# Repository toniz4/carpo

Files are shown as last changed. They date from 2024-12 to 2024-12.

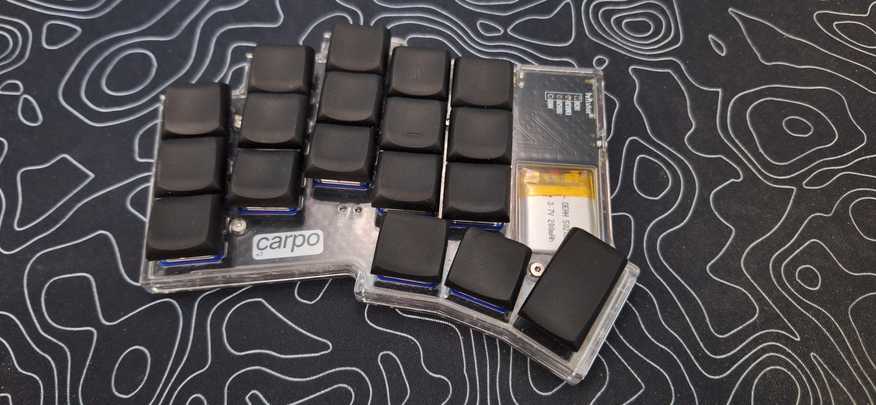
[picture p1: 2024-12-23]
assets/carpo_single.jpg

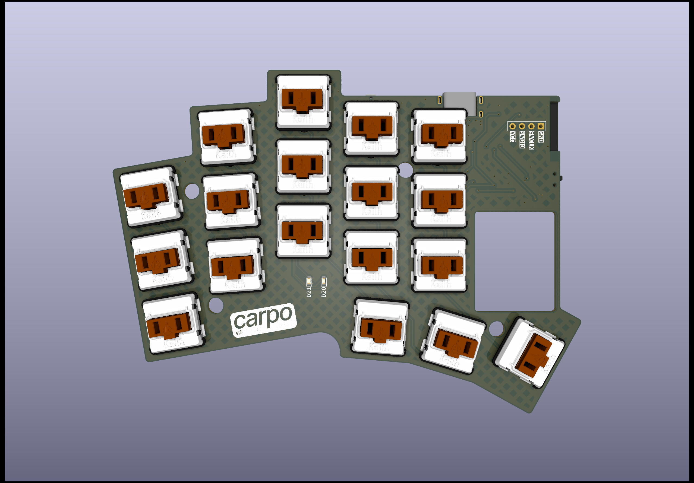
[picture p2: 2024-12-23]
assets/carpo_pcb_render_top.png

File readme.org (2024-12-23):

#+BEGIN_HTML html
<picture align="center">
  <source media="(prefers-color-scheme: dark)" srcset="/assets/carpo_logo_dark.svg">
  <source media="(prefers-color-scheme: light)" srcset="/assets/carpo_logo_light.svg">
  <img alt="carpo logo" src="/assets/carpo_logo_light.svg">
</picture>
#+END_HTML

Carpo is a 36 keys, low profile, choc spaced, split keyboard. Based on the Holyiot 18010 BLE module.

It features kailh choc v1 switches, a 200mah battery, status led and a thin and sleek case.

#+BEGIN_HTML html
<img alt="carpo both" src="/assets/carpo_both.jpg">
<details>
<summary>More photos</summary>
<img alt="carpo bottom" src="/assets/carpo_bottom.jpg">
<img alt="carpo single" src="/assets/carpo_single.jpg">
<p>The case is printed in JLCPCB using the 8001 resin</p>
<p>The keycaps are Pseudoku's Chicago Stenographer, printed in JLCPCB using the JLC black resin.</p>

<h2>PCB renders</h2>
<img alt="carpo pcb render top" src="/assets/carpo_pcb_render_top.png">
<img alt="carpo pcb render bottom" src="/assets/carpo_pcb_render_bottom.png">
</details>
#+END_HTML

The blue status LED will blink showing the Bluetooth status, if it's breathing it's disconnected. After connecting, it will blink a number of times, corresponding to the index of the current Bluetooth profile (profile 0 will blink 1 time, profile 1, 2 times, etc.)

** PCB

The PCB gerbers are in [[./pcb/gerbers/left_gerber.zip]] and [[./pcb/gerbers/right_gerber.zip]]

*** BOM

This is the BOM for a single side, duplicate the quantity for both sides.

|------------+------------------------+-----+----------+------------|
| Reference  | Value                  | Qty | LCSC     | Aliexpress |
|------------+------------------------+-----+----------+------------|
| C1         | 1nF                    |   1 | C1588    | [[https://www.aliexpress.com/item/32966526545.html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][link]]       |
| C4,C5      | 4.7uF                  |   2 | C19666   | [[https://www.aliexpress.com/item/32966526545.html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][link]]       |
| C6,C7      | 1uF                    |   2 | C1592    | [[https://www.aliexpress.com/item/32966526545.html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][link]]       |
| D1...D18   | 1N4148                 |  18 | C909967  | [[https://www.aliexpress.com/item/32849879904.html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][link]]       |
| D19        | 1N5819W                |   1 | C169540  | [[https://www.aliexpress.com/item/32849879904.html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][link]]       |
| D20        | RED                    |   1 | C2286    | [[https://www.aliexpress.com/item/1005005981379885.html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][link]]       |
| D21        | Blue                   |   1 | C72041   | [[https://www.aliexpress.com/item/1005005981379885.html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][link]]       |
| ESD1       | USBLC6-2P6             |   1 | C3647099 | [[https://www.aliexpress.com/item/1005006444169732.html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][link]]       |
| F1         | 500mA                  |   1 | C269104  | [[https://www.aliexpress.com/item/1005005611093145.html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][link]]       |
| J1         | USB_C_Receptacle       |   1 | C168688  | [[https://www.aliexpress.com/item/1005006344850545.html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][link]]       |
| J2         | X1224WRS-02-LPV01      |   1 | C528028  | [[https://www.aliexpress.com/item/1005008059654298.html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][link]]       |
| Q1         | AO3401A                |   1 | C15127   | [[https://www.aliexpress.com/item/32491247912.html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][link]]       |
| R1,R2      | 5.1K                   |   2 | C23186   | [[https://www.aliexpress.com/item/32847135098.html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][link]]       |
| R3         | 1M                     |   1 | C22935   | [[https://www.aliexpress.com/item/32847135098.html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][link]]       |
| R4         | 100k                   |   1 | C25803   | [[https://www.aliexpress.com/item/32847135098.html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][link]]       |
| R5,R9      | 1K                     |   2 | C21190   | [[https://www.aliexpress.com/item/32847135098.html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][link]]       |
| R6         | RPROG*                 |   1 | C22978   | [[https://www.aliexpress.com/item/32847135098.html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][link]]       |
| R7         | 806/820k               |   1 | C103828  | [[https://www.aliexpress.com/item/1005005180820900.html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][link]]       |
| R8         | 2M                     |   1 | C22976   | [[https://www.aliexpress.com/item/32847135098.html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][link]]       |
| R_TACT1    | SW_Push                |   1 | C79175   | [[https://www.aliexpress.com/item/1005005453787620.html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][link]]       |
| SW1...SW18 | SW_SPST                |  18 | NA       | [[https://www.aliexpress.com/item/1005004290562374.html?spm=a2g0o.order_list.order_list_main.11.1b7a1802tGxfP6][link]]       |
| SW19       | PCM12SMTR              |   1 | C221841  | [[https://www.aliexpress.com/item/4000685483225.html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][link]]       |
| U1         | nRF52840_holyiot_18010 |   1 | NA       | [[https://www.aliexpress.com/item/32951888809.html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][link]]       |
| U2         | XC6206P332MR-G         |   1 | C5446    | [[https://www.aliexpress.com/item/1005005560879957.html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][link]]       |
| U3         | MCP73831               |   1 | C14879   | [[https://www.aliexpress.com/item/32714249253.html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][link]]       |
| NA         | 502025                 |   1 | NA       | [[https://www.aliexpress.com/item/1005007356459315.html?gatewayAdapt=glo2bra][link]]       |
| NA         | 781720002*             |   1 | NA       | [[https://www.aliexpress.com/item/1005004784691542.html?gatewayAdapt=glo2bra][link]]       |
|------------+------------------------+-----+----------+------------|

- RPROG: You can use 5.1K resistors already included for the USB-C. See schematic for RPROG values, keep it at max 500mA.
- 781720002: Buy the J003 option.

** Case

It's recommended to print in resin, printing in FDM printers was not tested.

Currently, some walls near the battery switch and reset are too thin, if you are printing with jlcpcb they may complain about that. I will fix this in a future version. But the result came out fine.

*** BOM
|--------------------------+----------+------------|
| Component                | Quantity | Aliexpress |
|--------------------------+----------+------------|
| M2 Countersunk screw 8mm |        8 | [[https://pt.aliexpress.com/item/32968368588.html?gatewayAdapt=glo2bra][link]]       |
| M2 Nut                   |        8 | [[https://pt.aliexpress.com/item/1005003121029934.html?gatewayAdapt=glo2bra][link]]       |
| 8x1.5mm Rubber Feet      |        8 | [[https://www.aliexpress.com/item/1005002620133214.html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][link]]       |
| [[./case/top_left.stl][Left Top case]]            |        1 |            |
| [[./case/bottom_left.stl][Left Bottom case]]         |        1 |            |
| [[./case/top_right.stl][Right top case]]           |        1 |            |
| [[./case/bottom_right.stl][Right bottom case]]        |        1 |            |
|--------------------------+----------+------------|

** Building
*** PCB

The PCB is not easily hand solderable, I would recommend using a hotplate (I used [[https://pt.aliexpress.com/item/1005006380693061.html?gatewayAdapt=glo2bra][this]] one), or a rework station. Also some pads in the holyiot 18010 are not accessible for hand soldering.
Put solder paste in the pads and place the components. You can use as a reference the [[./pcb/left/bom/ibom.html][left ibom]] and [[./pcb/right/bom/ibom.html][right ibom]].
After that, ensure that there is no shorts.

*** Battery

To solder the cable included in the BOM to the battery, you can solder the cables directly to the battery cables, or unsolder the original battery cables, and solder the included cables to the battery.
*MAKE SURE TO NOT SHORT THE POSITIVE AND NEGATIVE LEADS, ESPECIALLY WHEN TRYING TO RUN THE CABLES WITH TWEEZERS TO THE SIDE OF THE BATTERY, DON'T ASK ME HOW I KNOW THIS*

** Firmware
*** Bootloader

Carpo uses the Adafruit nRF52 Bootloader. You can get it in this [[https://github.com/toniz4/Adafruit_nRF52_Bootloader][fork]]. The nrfmicro wiki
has a great section on flashing the bootloader, you can get it [[https://github.com/joric/nrfmicro/wiki/Bootloader][here]], but following the
build and flash sections of the Adafruit repo worked well for me. I used a rpi pico
flashed with [[https://github.com/raspberrypi/debugprobe][debugprobe]]. The SWD pins are accessible at the top of the PCB.

After flashing the bootloader, you should be able to double press the reset button to
enter in the bootloader mode, the blue status LED should breathe and it should appear as a
flash drive in your computer.

*** ZMK

The ZMK config can be found in this [[https://github.com/toniz4/zmk-config-carpo][repo]]. Just put the keyboard in bootloader mode, get the .uf2 firmware in the latest build [[https://github.com/toniz4/zmk-config-carpo/actions][artifact]], and copy the respective left and right .uf2 file to the left and right keyboard.

The layout is pretty barebones, so customize as you wish. In the ~personal~ branch I have the layout that I personally use.

** Credits and inspirations

It's thanks to various open source projects that I was able to make the Carpo keyboard.

- [[https://github.com/GEIGEIGEIST/TOTEM][TOTEM]]: Layout inspirations.
- [[https://github.com/yumagulovrn/dao-choc-ble?tab=readme-ov-file][Dao Choc BLE]]: Schematic design and PCB Layout.
- [[https://github.com/cacheworks/Wubbo][Wubbo]]: Schematic design.
- [[https://github.com/joric/nrfmicro][nRFMicro]] Schematic design and documentation, if it weren't for the nRFMicro documentation, this project wouldn't be possible.
- [[https://lowprokb.ca/products/corne-ish-zen][Corne-ish Zen]]: Case design and PCB Layout.

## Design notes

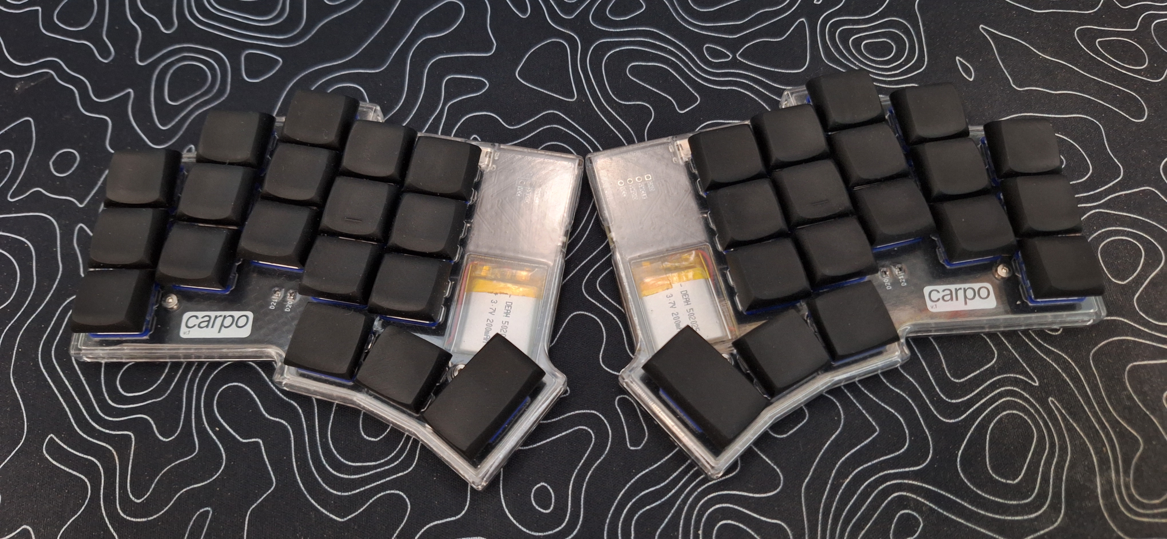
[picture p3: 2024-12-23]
assets/carpo_both.jpg

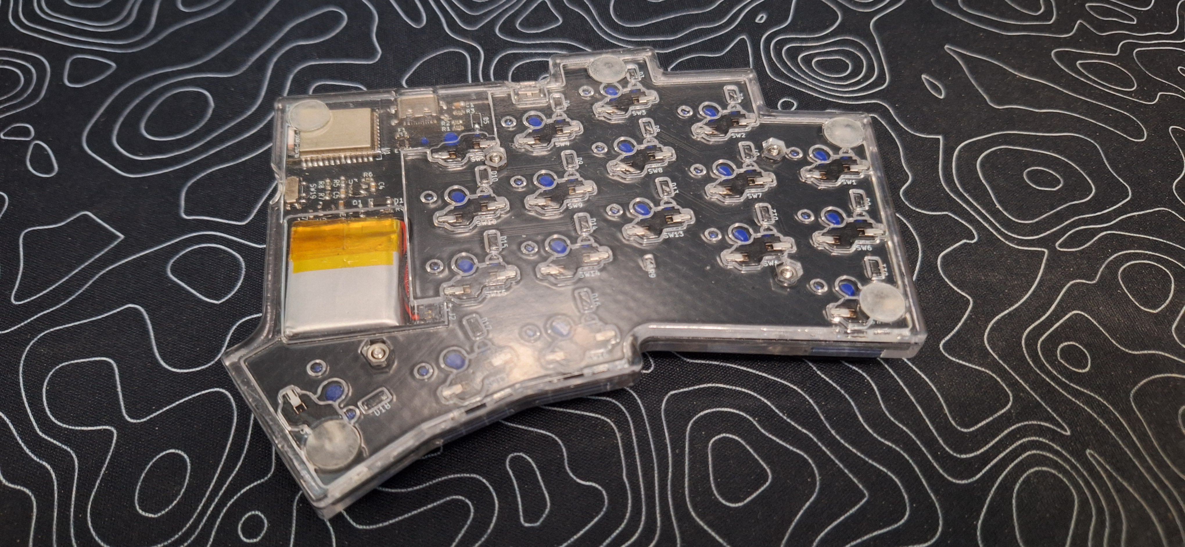
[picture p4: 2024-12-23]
assets/carpo_bottom.jpg

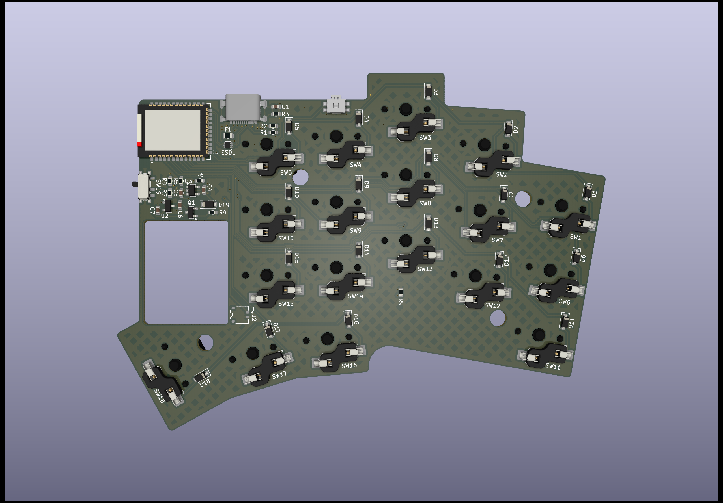
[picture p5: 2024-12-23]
assets/carpo_pcb_render_bottom.png

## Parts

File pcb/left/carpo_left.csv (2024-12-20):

Reference | Value | Footprint | Qty | DNP | LCSC
C1 | 1nF | Capacitor_SMD:C_0603_1608Metric | 1 |  | C1588
C4,C5 | 4.7uF | Capacitor_SMD:C_0603_1608Metric | 2 |  | C19666
C6,C7 | 1uF | Capacitor_SMD:C_0603_1608Metric | 2 |  | C1592
D1,D2,D3,D4,D5,D6,D7,D8,D9,D10,D11,D12,D13,D14,D15,D16,D17,D18 | 1N4148 | Diode_SMD:D_SOD-123 | 18 |  | C909967
D19 | 1N5819W | Diode_SMD:D_SOD-123 | 1 |  | C169540
D20 | RED | LED_SMD:LED_0603_1608Metric | 1 |  | C284922
D21 | Blue LED | LED_SMD:LED_0603_1608Metric | 1 |  | C125103
ESD1 | USBLC6-2P6 | Package_TO_SOT_SMD:SOT-666 | 1 |  | C3647099
F1 | 500mA | Fuse:Fuse_0805_2012Metric | 1 |  | C269104
J1 | USB_C_Receptacle | carpo:USB-C_C168688 | 1 |  | C168688
J2 | X1224WRS-02-LPV01 | Connector_Molex:Molex_Pico-EZmate_78171-0002_1x02-1MP_P1.20mm_Vertical | 1 |  | C528028
JSWD1 | SWD | carpo:Header_SWD | 1
Q1 | AO3401A | Package_TO_SOT_SMD:SOT-23 | 1 |  | C15127
R1,R2 | 5.1K | Resistor_SMD:R_0603_1608Metric | 2 |  | C23186
R3 | 1M | Resistor_SMD:R_0603_1608Metric | 1 |  | C22935
R4 | 100k | Resistor_SMD:R_0603_1608Metric | 1 |  | C25803
R5,R9 | 1K | Resistor_SMD:R_0603_1608Metric | 2 |  | C21190
R6 | RPROG | Resistor_SMD:R_0603_1608Metric | 1 |  | C22978
R7 | 806/820k | Resistor_SMD:R_0603_1608Metric | 1 |  | C103828
R8 | 2M | Resistor_SMD:R_0603_1608Metric | 1 |  | C22976
R_TACT1 | SW_Push | Button_Switch_SMD:Panasonic_EVQPUL_EVQPUC | 1 |  | C79175
SW1,SW2,SW3,SW4,SW5,SW6,SW7,SW8,SW9,SW10,SW11,SW12,SW13,SW14,SW15,SW16,SW17,SW18 | SW_SPST | -- mixed values -- | 18
SW19 | PCM12SMTR | Button_Switch_SMD:SW_SPDT_PCM12 | 1 |  | C221841
U1 | nRF52840_holyiot_18010 | marbastlib-various:nRF52840_holyiot_18010 | 1
U2 | XC6206P LDO | Package_TO_SOT_SMD:SOT-23 | 1 |  | C5446
U3 | MCP73831 | Package_TO_SOT_SMD:SOT-23-5 | 1 |  | C14879

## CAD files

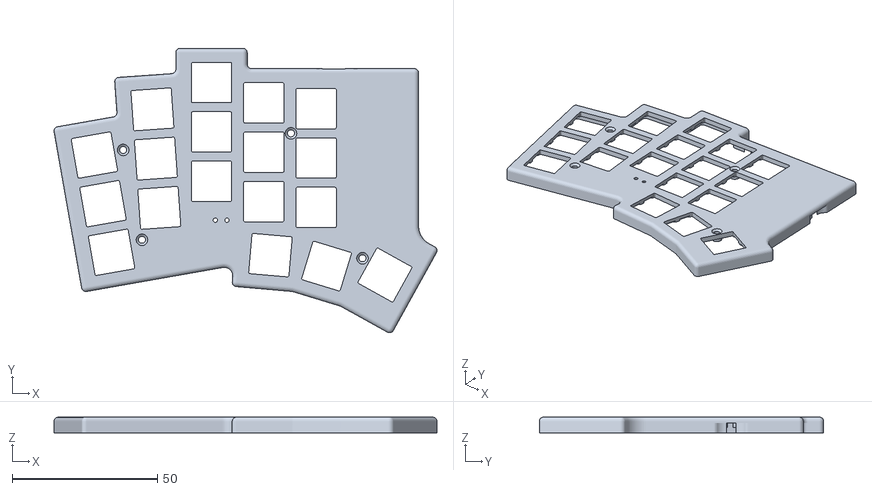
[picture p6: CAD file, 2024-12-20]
case/top_left.stl
131.9 x 97.9 x 5.43

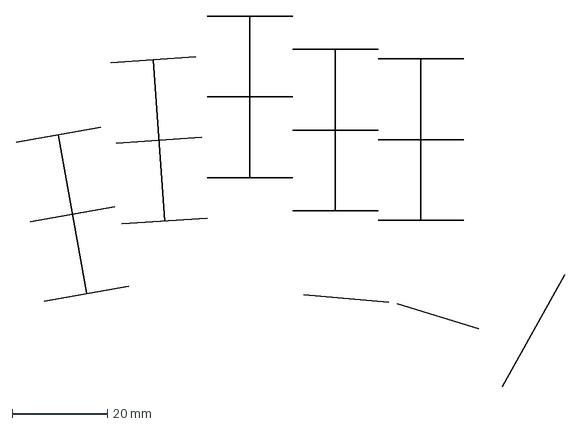
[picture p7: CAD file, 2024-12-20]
pcb/switch_pos.dxf
115.4 x 78.1 mm

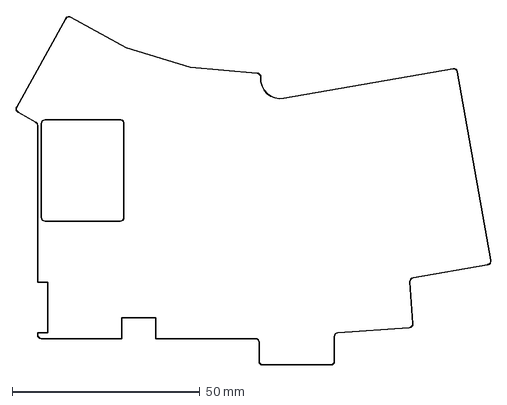
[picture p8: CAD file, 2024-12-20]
pcb/pcb.dxf
126.4 x 92.8 mm

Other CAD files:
case/top_right.stl

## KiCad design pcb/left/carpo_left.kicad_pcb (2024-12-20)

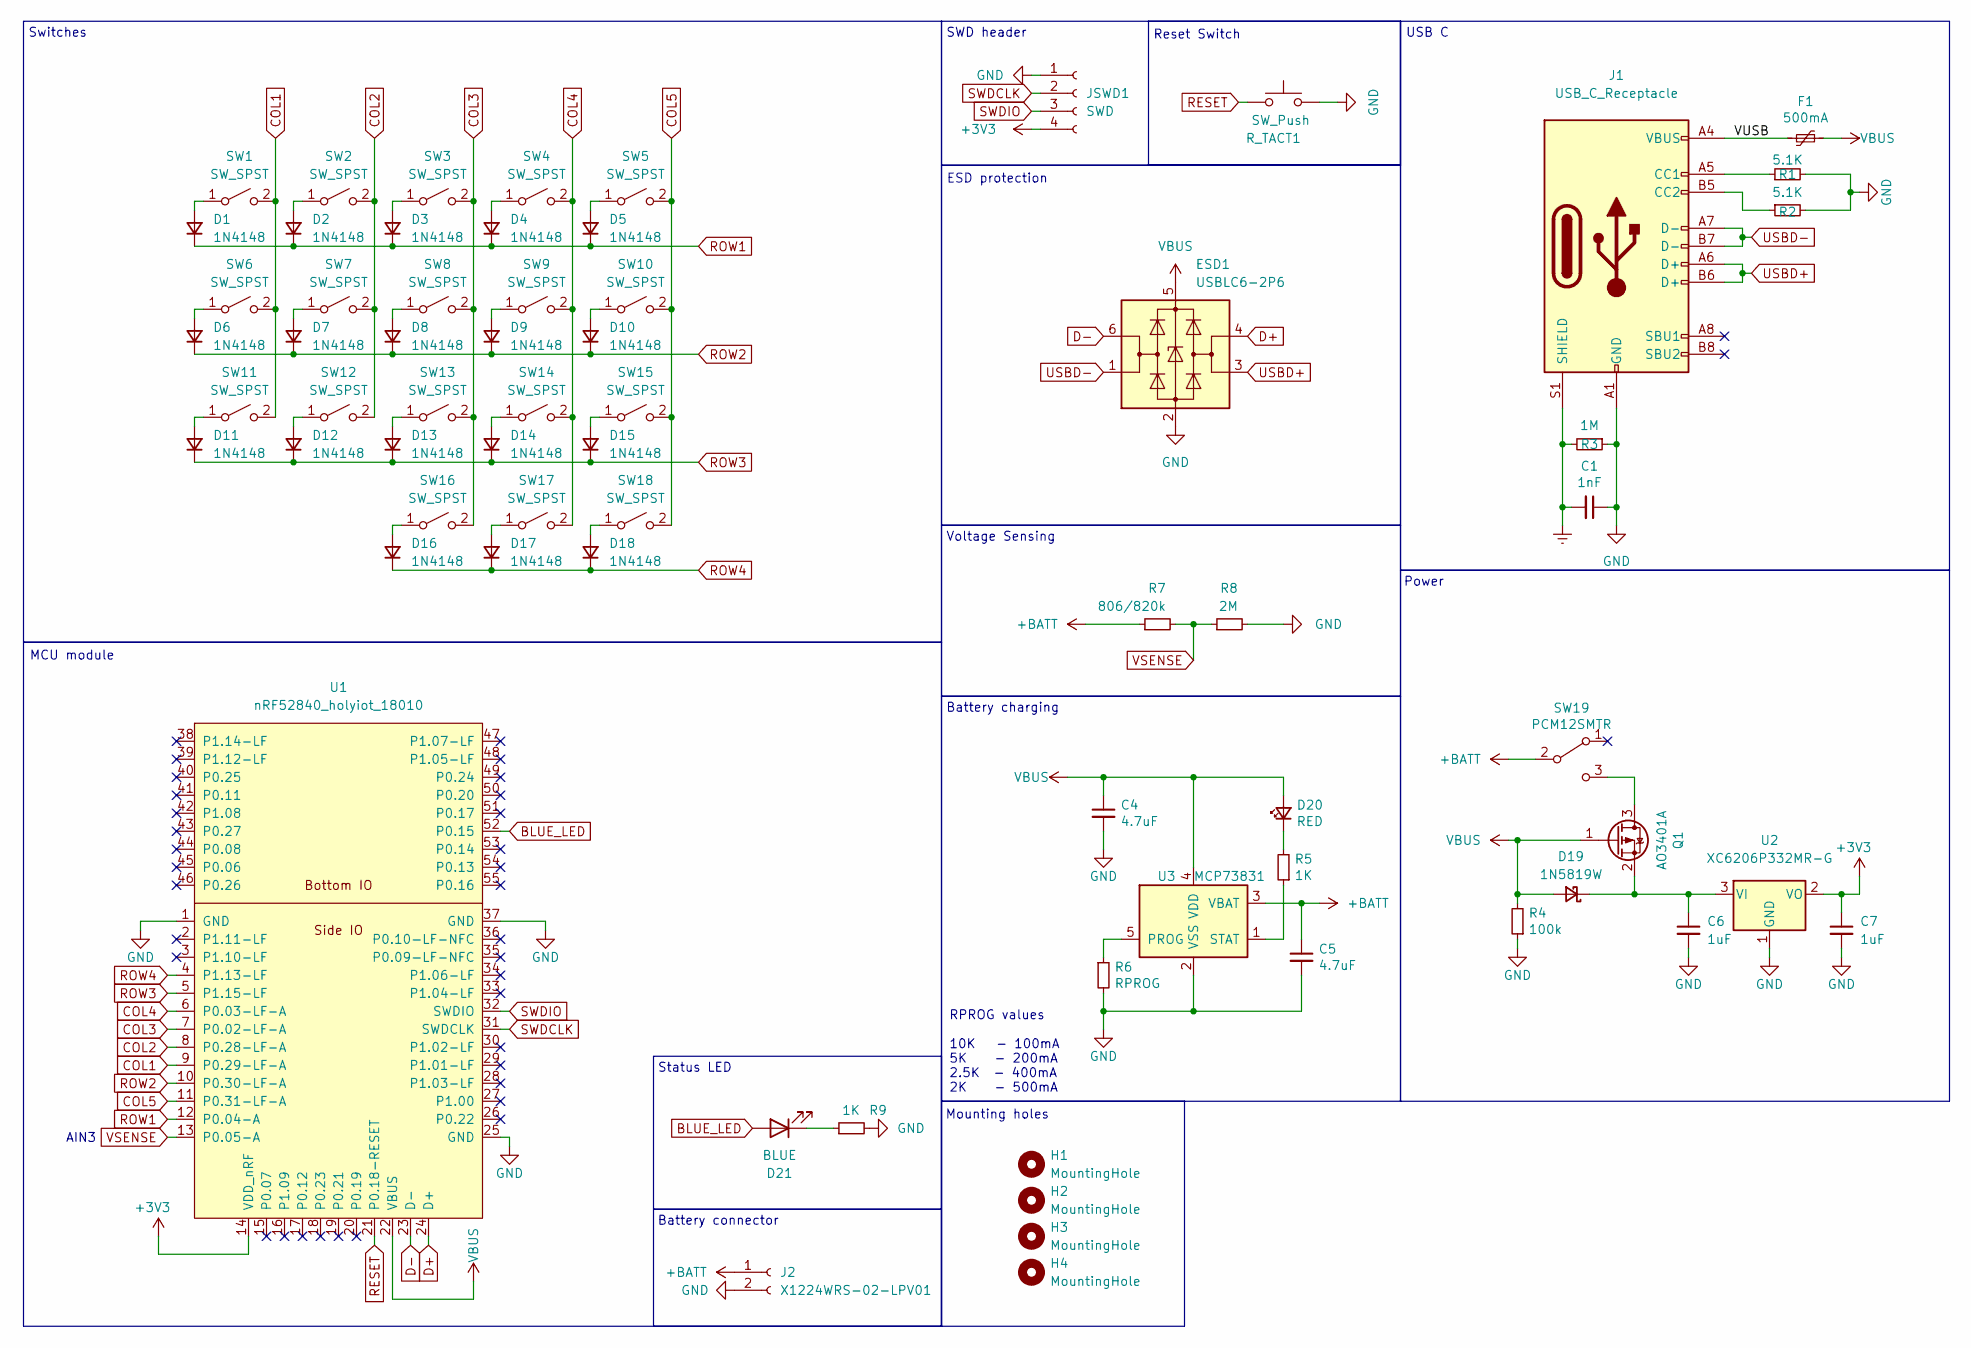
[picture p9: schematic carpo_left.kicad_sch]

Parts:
C1: 1nF; C_0603_1608Metric; LCSC C1588
C4, C5: 4.7uF; C_0603_1608Metric; LCSC C19666
C6, C7: 1uF; C_0603_1608Metric; LCSC C1592
D1, D2, D3, D4, D5, D6, D7, D8, D9, D10, D11, D12, D13, D14, D15, D16, D17, D18: 1N4148; D_SOD-123; LCSC C909967
D19: 1N5819W; D_SOD-123; LCSC C169540
D20: RED; LED_0603_1608Metric; LCSC C2286
D21: BLUE; LED_0603_1608Metric; LCSC C72041
ESD1: USBLC6-2P6; SOT-666; LCSC C3647099
F1: 500mA; Fuse_0805_2012Metric; LCSC C269104
H1, H2, H3, H4: MountingHole; StandoffHole_4.3mm
J1: USB_C_Receptacle; USB-C_C168688; LCSC C168688
J2: X1224WRS-02-LPV01; Molex_Pico-EZmate_78171-0002_1x02-1MP_P1.20mm_Vertical; LCSC C528028
JSWD1: SWD; Header_SWD
Q1: AO3401A; SOT-23; LCSC C15127
R1, R2: 5.1K; R_0603_1608Metric; LCSC C23186
R3: 1M; R_0603_1608Metric; LCSC C22935
R4: 100k; R_0603_1608Metric; LCSC C25803
R5, R9: 1K; R_0603_1608Metric; LCSC C21190
R6: RPROG; R_0603_1608Metric; LCSC C22978
R7: 806/820k; R_0603_1608Metric; LCSC C103828
R8: 2M; R_0603_1608Metric; LCSC C22976
R_TACT1: SW_Push; Panasonic_EVQPUL_EVQPUC; LCSC C79175
SW1, SW2, SW3, SW4, SW5, SW6, SW7, SW8, SW9, SW10, SW11, SW12, SW13, SW14, SW15, SW16, SW17: SW_SPST; SW_choc_v1_HS_CPG135001S30_1u
SW18: SW_SPST; SW_choc_v1_HS_CPG135001S30_1.5u
SW19: PCM12SMTR; SW_SPDT_PCM12; LCSC C221841
U1: nRF52840_holyiot_18010
U2: XC6206P332MR-G; SOT-23; LCSC C5446
U3: MCP73831; SOT-23-5; LCSC C14879

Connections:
+3V3: C7.1, JSWD1.4, U1.14 (VDD_nRF), U2.2 (VO)
+BATT: C5.1, J2.1, R7.1, SW19.2 (B), U3.3 (VBAT)
/VUSB: F1.2, J1.A4 (VBUS), J1.A9 (VBUS), J1.B4 (VBUS), J1.B9 (VBUS)
BLUE_LED: D21.2 (A), U1.52 (P0.15)
COL1: SW1.2 (B), SW6.2 (B), SW11.2 (B), U1.9 (P0.29-LF-A)
COL2: SW2.2 (B), SW7.2 (B), SW12.2 (B), U1.8 (P0.28-LF-A)
COL3: SW3.2 (B), SW8.2 (B), SW13.2 (B), SW16.2 (B), U1.7 (P0.02-LF-A)
COL4: SW4.2 (B), SW9.2 (B), SW14.2 (B), SW17.2 (B), U1.6 (P0.03-LF-A)
COL5: SW5.2 (B), SW10.2 (B), SW15.2 (B), SW18.2 (B), U1.11 (P0.31-LF-A)
D+: ESD1.4 (I/O2), U1.24 (D+)
D-: ESD1.6 (I/O1), U1.23 (D-)
Earth: C1.2, J1.S1 (SHIELD), R3.2
GND: C1.1, C4.2, C5.2, C6.2, C7.2, ESD1.2 (GND), J1.A1 (GND), J1.A12 (GND), J1.B1 (GND), J1.B12 (GND), J2.2, JSWD1.1, R1.2, R2.2, R3.1, R4.1, R6.2, R8.2, R9.2, R_TACT1.2, U1.1 (GND), U1.25 (GND), U1.37 (GND), U2.1 (GND), U3.2 (VSS)
unnamed: D1.2 (A), SW1.1 (A)
unnamed: D2.2 (A), SW2.1 (A)
unnamed: D3.2 (A), SW3.1 (A)
unnamed: D4.2 (A), SW4.1 (A)
unnamed: D5.2 (A), SW5.1 (A)
unnamed: D6.2 (A), SW6.1 (A)
unnamed: D7.2 (A), SW7.1 (A)
unnamed: D8.2 (A), SW8.1 (A)
unnamed: D9.2 (A), SW9.1 (A)
unnamed: D10.2 (A), SW10.1 (A)
unnamed: D11.2 (A), SW11.1 (A)
unnamed: D12.2 (A), SW12.1 (A)
unnamed: D13.2 (A), SW13.1 (A)
unnamed: D14.2 (A), SW14.1 (A)
unnamed: D15.2 (A), SW15.1 (A)
unnamed: D16.2 (A), SW16.1 (A)
unnamed: D17.2 (A), SW17.1 (A)
unnamed: D18.2 (A), SW18.1 (A)
unnamed: C6.1, D19.1 (K), Q1.2 (S), U2.3 (VI)
unnamed: D20.1 (K), R5.2
unnamed: D21.1 (K), R9.1
unnamed: J1.A5 (CC1), R1.1
unnamed: J1.B5 (CC2), R2.1
unnamed: Q1.3 (D), SW19.3 (C)
unnamed: R6.1, U3.5 (PROG)
unnamed: R5.1, U3.1 (STAT)
RESET: R_TACT1.1, U1.21 (P0.18-RESET)
ROW1: D1.1 (K), D2.1 (K), D3.1 (K), D4.1 (K), D5.1 (K), U1.12 (P0.04-A)
ROW2: D6.1 (K), D7.1 (K), D8.1 (K), D9.1 (K), D10.1 (K), U1.10 (P0.30-LF-A)
ROW3: D11.1 (K), D12.1 (K), D13.1 (K), D14.1 (K), D15.1 (K), U1.5 (P1.15-LF)
ROW4: D16.1 (K), D17.1 (K), D18.1 (K), U1.4 (P1.13-LF)
SWDCLK: JSWD1.2, U1.31 (SWDCLK)
SWDIO: JSWD1.3, U1.32 (SWDIO)
USBD+: ESD1.3 (I/O2), J1.A6 (D+), J1.B6 (D+)
USBD-: ESD1.1 (I/O1), J1.A7 (D-), J1.B7 (D-)
VBUS: C4.1, D19.2 (A), D20.2 (A), ESD1.5 (VBUS), F1.1, Q1.1 (G), R4.2, U1.22 (VBUS), U3.4 (VDD)
VSENSE: R7.2, R8.1, U1.13 (P0.05-A)

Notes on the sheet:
Battery charging
Power
RPROG values 10K - 100mA 5K - 200mA 2.5K - 400mA 2K - 500mA
Mounting holes
SWD header
AIN3
Switches
Voltage Sensing
USB C
Status LED
Battery connector
MCU module
Reset Switch
ESD protection

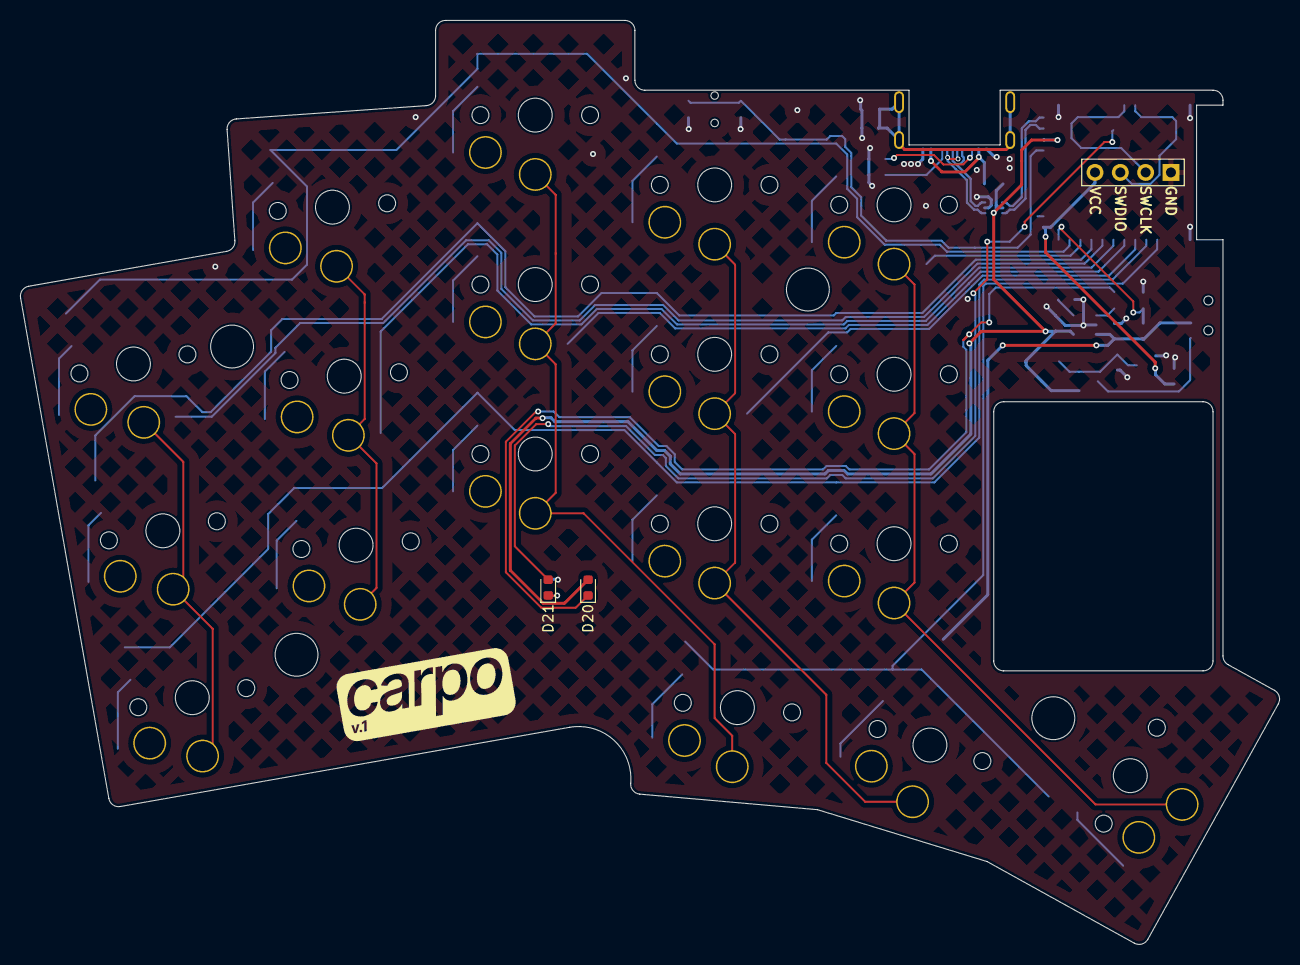
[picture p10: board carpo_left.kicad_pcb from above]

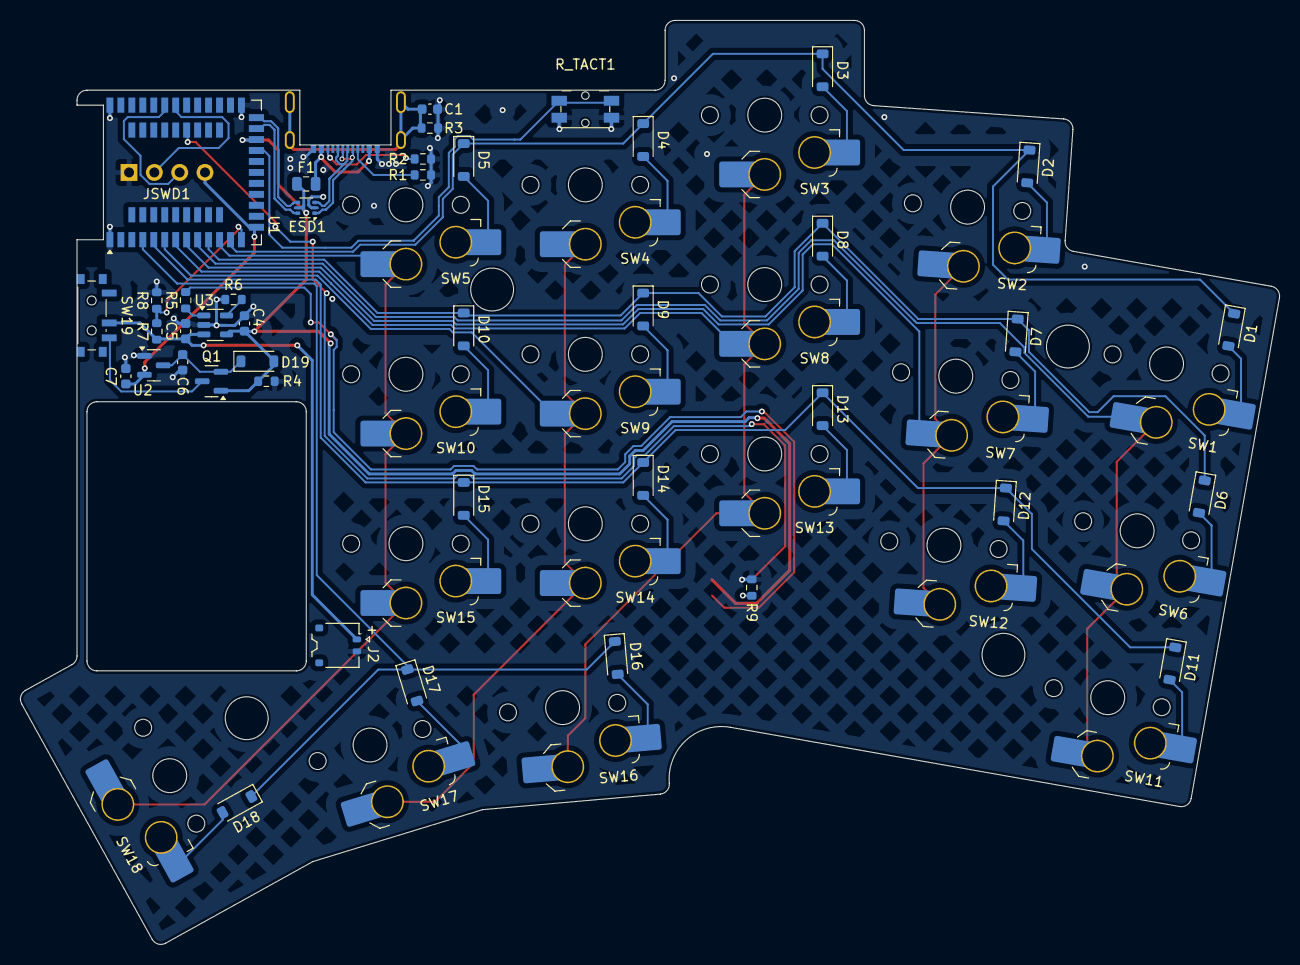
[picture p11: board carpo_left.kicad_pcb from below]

Board: 2 copper layers, 126.3 x 92.7 mm, 68 parts (61 on the bottom side), 50 nets.

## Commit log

2024-06-18 add left right
    [carpo_left.kicad_sch, carpo_right.kicad_sch]
2024-12-20 latest carpo version
    [carpo.kicad_sch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]
